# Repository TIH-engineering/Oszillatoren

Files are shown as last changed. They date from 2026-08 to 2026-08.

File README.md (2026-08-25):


Build


# LA – Oszillatoren

## 🔌 Leiterplattenbeschreibung

Die Leiterplatte **LA – Oszillatoren** wurde für Laborübungen im Bereich
Elektronik und Hardwareentwicklung entwickelt. Sie ermöglicht die praktische
Untersuchung unterschiedlicher Oszillatorschaltungen und den Vergleich ihrer
Funktionsprinzipien und Eigenschaften.

Auf einer gemeinsamen Leiterplatte sind mehrere typische Oszillatorschaltungen
realisiert:

- **RC-Phasenschieber-Oszillator**
- **Wien-Brücken-Oszillator**
- **OPV-Relaxationsoszillator**
- **RC-/Quarzoszillatoren**

Die Schaltungen sind räumlich voneinander getrennt aufgebaut und verfügen über
gut zugängliche Messpunkte. Dadurch können charakteristische Signale direkt mit
dem Oszilloskop untersucht und mit den theoretisch berechneten Größen verglichen
werden.

Bei ausgewählten Schaltungen sind Bauteile steck- bzw. austauschbar ausgeführt.
Damit können beispielsweise unterschiedliche Widerstandswerte eingesetzt und
deren Einfluss auf Frequenz und Schwingverhalten experimentell untersucht werden.

Die Leiterplatte wird mit **+5 V / GND / −5 V** versorgt. Die einzelnen
Messpunkte und Anschlüsse sind direkt auf der Leiterplatte beschriftet.

> **Einsatzgebiet:** Laborunterricht zur Untersuchung von Oszillatoren,
> Schwingbedingungen, Frequenzbestimmung und dem Einfluss einzelner Bauteile.

---

# 📥 Downloads

| Datei | Beschreibung |
|:---|:---|
| 📄 Schaltplan (PDF) | [`schematic.pdf`](../../releases/latest/download/schematic.pdf) |
| 🖨 Leiterplatte (PDF) | [`pcb.pdf`](../../releases/latest/download/pcb.pdf) |
| 🔩 Bohrplan | [`drill.pdf`](../../releases/latest/download/drill.pdf) |
| 📋 Stückliste (Excel) | [`bom.xlsx`](../../releases/latest/download/bom.xlsx) |
| 🌐 Interactive BOM | [`ibom.html`](../../releases/latest/download/ibom.html) |
| 📦 Fertigungsdaten | [`kicad.zip`](../../releases/latest/download/kicad.zip) |
| 🧊 STEP-Modell | [`pcb.step`](../../releases/latest/download/pcb.step) |

---

# 🖥 Leiterplatte

## Vorschau

| Oberseite | Unterseite |
|:---:|:---:|
|  |  |

## Oberseite



## Unterseite



---

# ℹ Projektinformationen

| Eigenschaft | Wert |
|---|---|
| Projekt | LA – Oszillatoren |
| Software | KiCad 10 |
| Repository | TIH-engineering/Oszillatoren |
| Lizenz | CC BY-NC-SA 4.0 |

---

# 🚀 Releases

Jeder Release enthält automatisch:

- Gerberdaten
- Bohrdaten
- Stückliste (Excel)
- Interactive BOM
- STEP-Modell
- Schaltplan als PDF
- Leiterplatte als PDF
- 3D-Renderings

Die jeweils aktuelle Version befindet sich unter **Releases**.

---

# 👨‍🏫 Autor

**HTL Rankweil**  
Labor Elektronik / Hardwareentwicklung

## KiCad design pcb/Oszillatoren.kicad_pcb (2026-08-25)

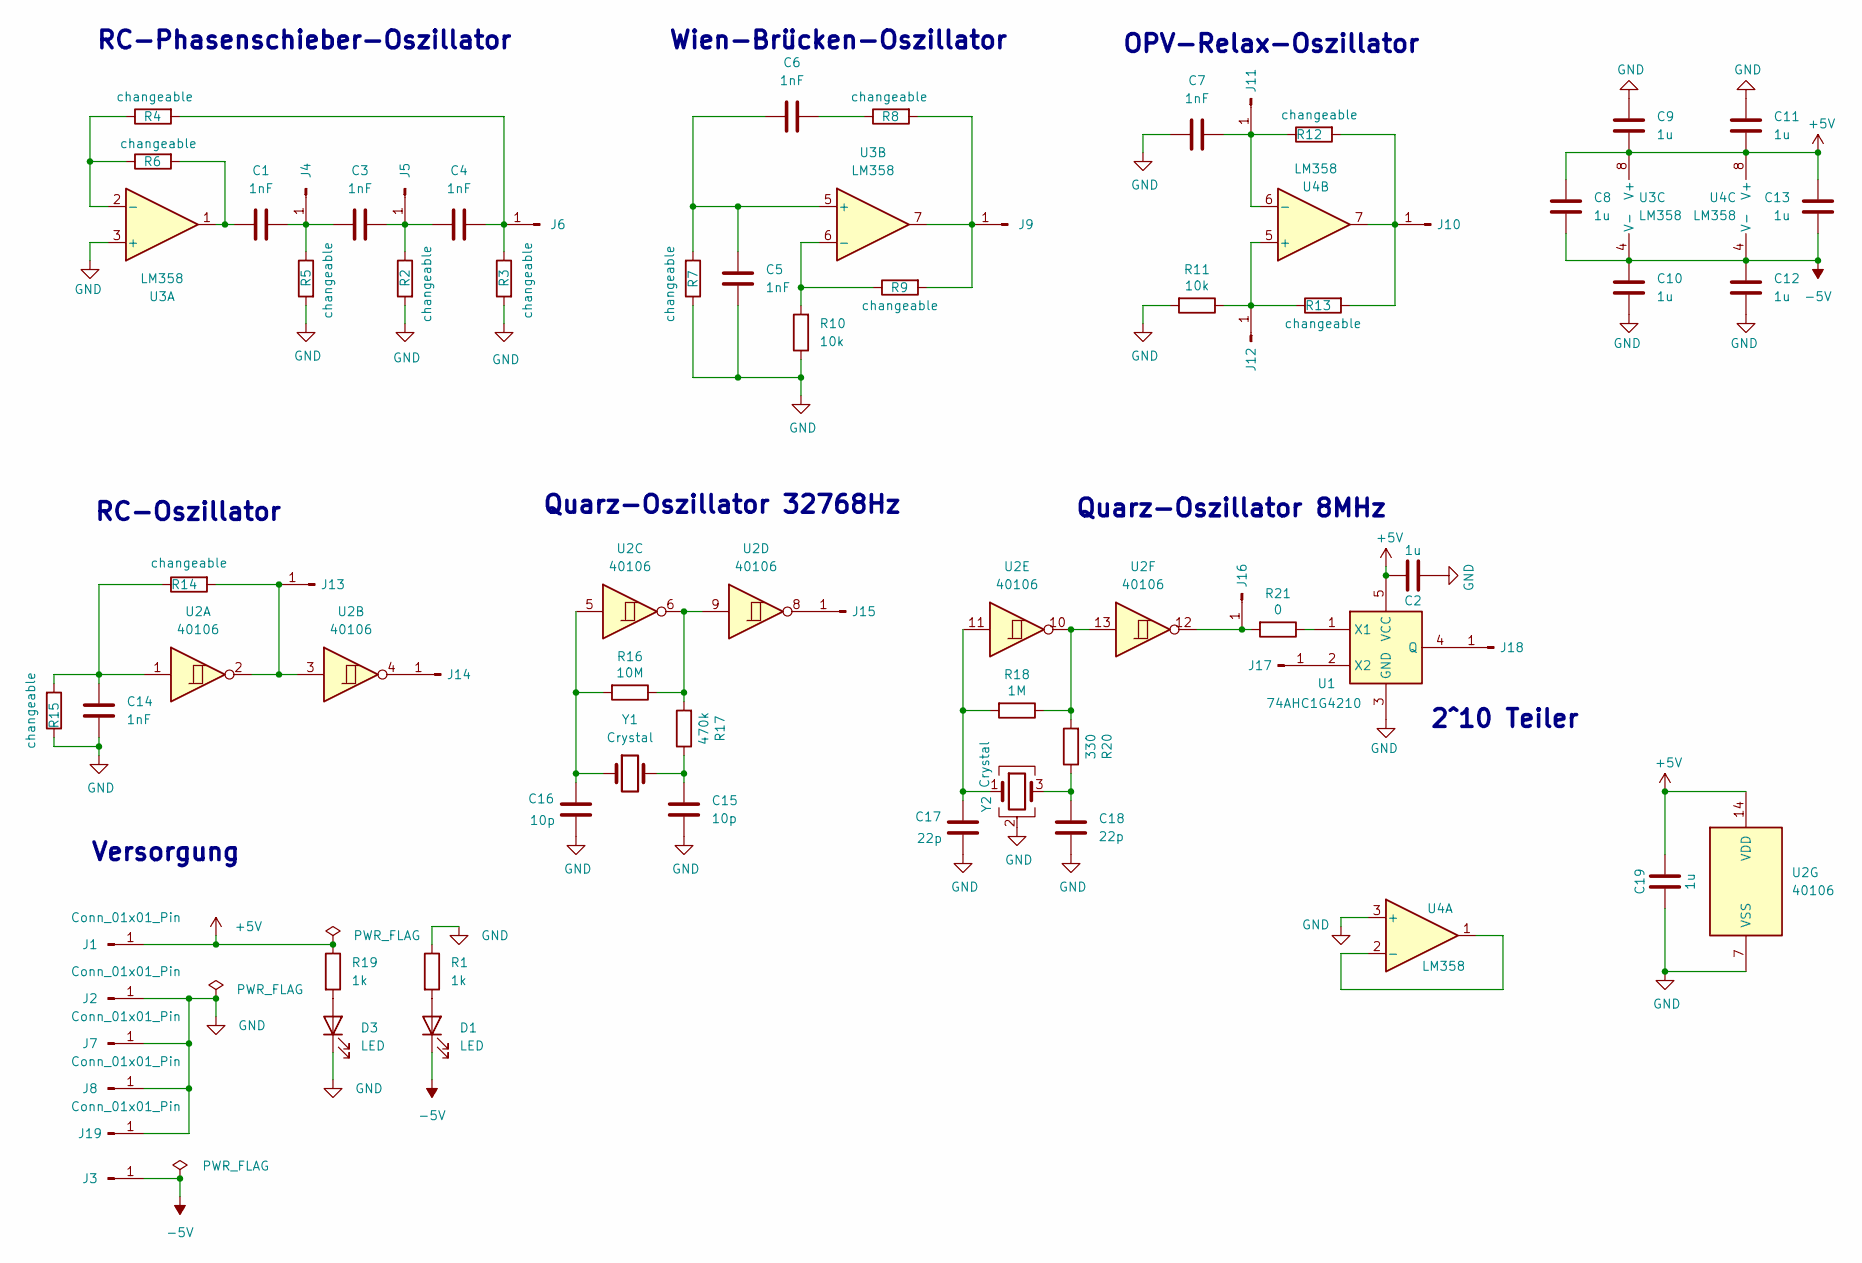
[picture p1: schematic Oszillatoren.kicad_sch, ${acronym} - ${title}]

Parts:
C1, C3, C4, C5, C6, C7, C14: 1nF; C_0805_2012Metric
C2, C8, C9, C10, C11, C12, C13, C19: 1u; C_1206_3216Metric
C15, C16: 10p; C_0603_1608Metric
C17, C18: 22p; C_0603_1608Metric
D1, D3: LED; LED_1206_3216Metric
J1, J2, J3, J4, J5, J6, J7, J8, J9, J10, J11, J12, J13, J14, J15, J16, J17, J18, J19: Conn_01x01_Pin; PinHeader_1x01_P2.54mm_Vertical
R1, R19: 1k; R_1206_3216Metric
R2, R3, R4, R5, R6, R7, R8, R9, R12, R13, R14, R15: 10k; R_axial_SMD-Adapter_P10.16mm_1mm
R10, R11: 10k; R_0805_2012Metric
R16: 10M; R_0805_2012Metric
R17: 470k; R_0805_2012Metric
R18: 1M; R_0805_2012Metric
R20: 330; R_0805_2012Metric
R21: 0; R_0805_2012Metric
U1: 74AHC1G4210; SOT-353_SC-70-5
U2: 40106; DIP-14_W7.62mm
U3, U4: LM358; DIP-8_W7.62mm
Y1: Crystal; Crystal_SMD_G8-2Pin_3.2x1.5mm_HandSoldering
Y2: Crystal; Crystal_SMD_EuroQuartz_MQ-4Pin_7.0x5.0mm_HandSoldering

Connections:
+5V: C2.1, C8.1, C9.1, C11.2, C13.1, C19.1, J1.1 (Pin_1_1), R19.1, U1.5 (VCC), U2.14 (VDD), U3.8 (V+), U4.8 (V+)
-5V: C8.2, C10.2, C12.1, C13.2, D1.1 (K), J3.1 (Pin_1_1), U3.4 (V-), U4.4 (V-)
GND: C2.2, C5.1, C7.2, C9.2, C10.1, C11.1, C12.2, C14.1, C15.2, C16.2, C17.2, C18.2, C19.2, D3.1 (K), J2.1 (Pin_1_1), J7.1 (Pin_1_1), J8.1 (Pin_1_1), J19.1 (Pin_1_1), R1.1, R2.2, R3.2, R5.2, R7.1, R10.1, R11.2, R15.1, U1.3 (GND), U2.7 (VSS), U3.3 (+), U4.3 (+), Y2.2 (G), Y2.4 (G)
unnamed: C1.1, R6.2, U3.1
unnamed: C6.2, R8.1
unnamed: C14.2, R14.1, R15.2, U2.1
unnamed: C15.1, R17.1, Y1.2
unnamed: C16.1, R16.2, U2.5, Y1.1
unnamed: C17.1, R18.2, U2.11, Y2.1
unnamed: C18.1, R20.1, Y2.3
unnamed: D1.2 (A), R1.2
unnamed: D3.2 (A), R19.2
unnamed: C1.2, C3.1, J4.1 (Pin_1_1), R5.1
unnamed: C3.2, C4.1, J5.1 (Pin_1_1), R2.1
unnamed: C4.2, J6.1 (Pin_1_1), R3.1, R4.2
unnamed: J9.1 (Pin_1_1), R8.2, R9.2, U3.7
unnamed: J10.1 (Pin_1_1), R12.2, R13.2, U4.7
unnamed: C7.1, J11.1 (Pin_1_1), R12.1, U4.6 (-)
unnamed: J12.1 (Pin_1_1), R11.1, R13.1, U4.5 (+)
unnamed: J13.1 (Pin_1_1), R14.2, U2.2, U2.3
unnamed: J14.1 (Pin_1_1), U2.4
unnamed: J15.1 (Pin_1_1), U2.8
unnamed: J16.1 (Pin_1_1), R21.2, U2.12
unnamed: J17.1 (Pin_1_1), U1.2 (X2)
unnamed: J18.1 (Pin_1_1), U1.4 (Q)
unnamed: R16.1, R17.2, U2.6, U2.9
unnamed: R18.1, R20.2, U2.10, U2.13
unnamed: R21.1, U1.1 (X1)
unnamed: R4.1, R6.1, U3.2 (-)
unnamed: C5.2, C6.1, R7.2, U3.5 (+)
unnamed: R9.1, R10.2, U3.6 (-)
unnamed: U4.1, U4.2 (-)

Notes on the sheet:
2^10 Teiler
RC-Oszillator
Versorgung
OPV-Relax-Oszillator
RC-Phasenschieber-Oszillator
Wien-Brücken-Oszillator
Quarz-Oszillator 8MHz
Quarz-Oszillator 32768Hz

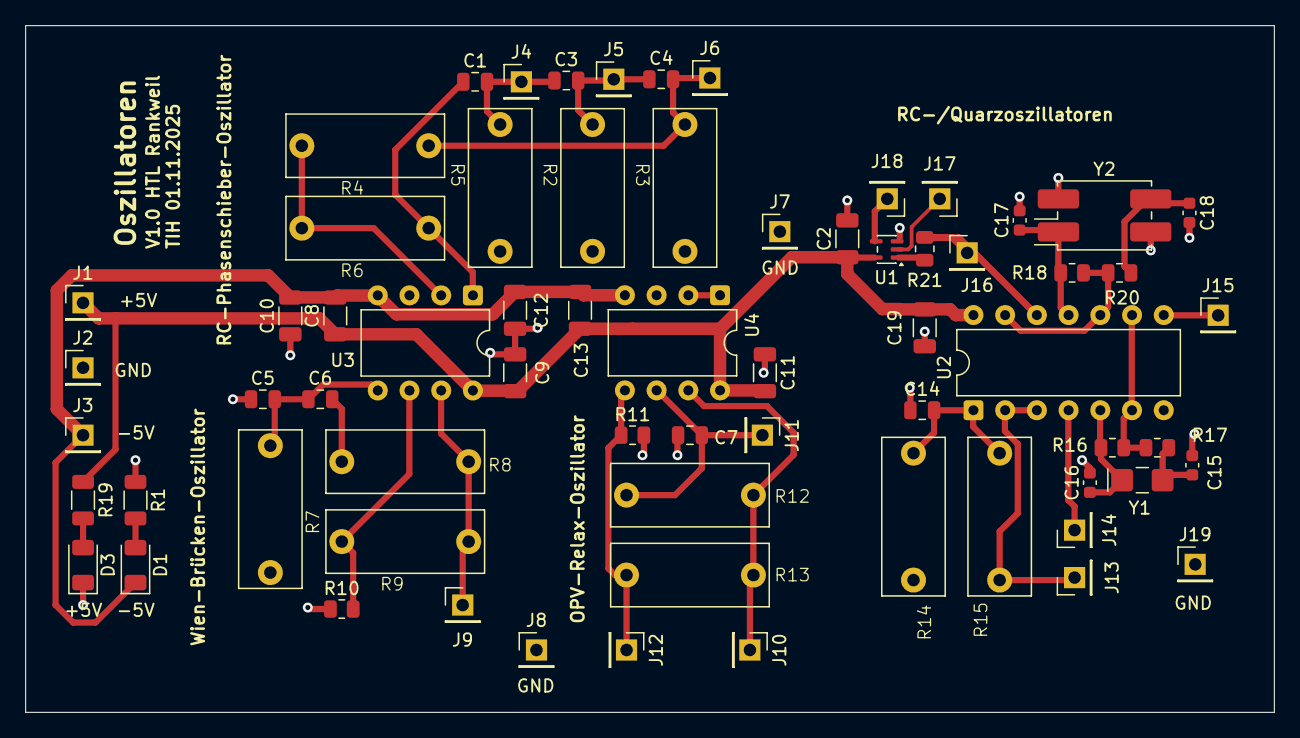
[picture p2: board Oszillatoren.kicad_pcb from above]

Board: 2 copper layers, 100.0 x 55.0 mm, 67 parts (0 on the bottom side), 32 nets.

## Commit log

2026-06-22 Replace demo project with Oszillatoren
    [Oszillatoren.kicad_pcb, Oszillatoren.kicad_sch, demo.kicad_pcb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]
2026-06-22 build und release angepasst Oszillatoren statt demo
2026-06-22 template schematic A4-landscape directory changed
2026-06-22 directory-change saved (landscape)
    [Oszillatoren.kicad_sch]
2026-06-22 footprint-library TIH added
    [Oszillatoren.kicad_pcb, Oszillatoren.kicad_sch]
2026-07-01 Use KiCad 10 for KiBot workflow
2026-07-01 Bibliotheken aktualisiert
    [Oszillatoren.kicad_pcb, Oszillatoren.kicad_sch]
2026-07-01 Bibliotheken und .sch File aktualisiert
    [Oszillatoren.kicad_sch]
2026-08-25 release-file 3D-view
    Tried to show the assembled parts
2026-08-25 Warnings solved
    [Oszillatoren.kicad_pcb]
2026-08-25 Warnings fixed
    [Oszillatoren.kicad_pcb]
2026-08-25 Changable Rs fixed
    [Oszillatoren.kicad_pcb, Oszillatoren.kicad_sch]
2026-08-25 all changable Rs fixed
    [Oszillatoren.kicad_pcb, Oszillatoren.kicad_sch]
2026-08-25 Crystal 3D-model changed
    [Oszillatoren.kicad_pcb]
2026-08-25 Changable R: 3D-Model added
    [Oszillatoren.kicad_pcb, Oszillatoren.kicad_sch]
2026-08-25 U2_U3_U4 neu zugeordnet
    [Oszillatoren.kicad_pcb]
